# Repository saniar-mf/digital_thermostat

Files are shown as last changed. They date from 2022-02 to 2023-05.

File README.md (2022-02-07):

# digital_thermostat
this project is a Digital Thermostat with arduino nano and SSD1306 128x32 Oled display with DS18B20 Temprature sensor.
this project works with 3.7 li-ion battery and relays can work together.anyway you can use usb charger or adaptor for powering up device.
also you can control your board with serial comminication or USB cable and desktop application.
PCB is ready and you can make it in 1 Layer.
## Board
board



-**In top-right you can change Relays source with jumpers between battery and adaptor jack**

-**You can choose the regulator based on the voltage of your relays**

-**If the relays are connected to the battery voltage source
Replace regulator َU1 with 15 ohm SMD resistor**

_**Remember Serial Comminication is for 3.3V so when you run your board with battery if your bluetooth madule had resistor in RX pin it filter your comminication.
best way is using bluetooth madules without boards or shorting RX in resistor**

## Serial Comminication
### board sends us this messages.
Prefix| Message | Description |
--- | --- | --- |
SN+| SettingUp | First Message when device turned on |
SN+| FirstStart | Board never used before |
SN+| Ready | Setup complite and ready to work |
SN+| SensorDetached | DS18B20 is not available |
SN+| SensorAttached | when sensor problem solved |
SN+| BatteryLow | Battery voltage is less than 3.75V and device not works |
SN+| BatteryOK | After connecting the charger and increasing the battery voltage to 3.75 volts |
SN+| SettingUpdate | When making changes to settings |
SN+| HT | Temperature is more than maximum temperature |
SN+| LT | Temperature is less than minimum temperature |
SN+| HPT | Temperature is more than (2/3 Avrage minimum and maximum) |
SN+| LPT | Temperature is less than (1/3 Avrage minimum and maximum) |
SN+| FIT | The temperature rises rapidly |
SN+| FDT | The temperature drops rapidly |
SN+| Normal | Temprature is normal |
SN+| {float} | Temprature value |

-**SN :To identify the message center (prevents interference if multiple boards are used)**

-**All messages are sent only once and are not repeated.If the temperature does not change, a new temperature message will not be sent**
### Getting information from board:
#### Commands:

 Command | response |
 --- | --- |
Get+ | SN+Temp+MinTemp+MaxTemp+AlarmEnable+HeaterEnable+CoolerEnable+VccVoltage+PowerSavingMode|
Get+T+ | SN+Temp |

Command | response |
 --- | --- |
 Set+MaxTemp+MinTemp+AlarmEnable+HeaterEnable+CoolerEnable+PowerSavingMode | SettingUpdate
  
  -If you do not want to change the numerical values, replace it with 200 and for logical values, replace it with 2 

## Desktop Application

psc1

writed with python and Qt5 can be used in Linux and Windows

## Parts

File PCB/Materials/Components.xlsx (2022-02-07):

Comment | Description | Designator | Footprint | LibRef | Quantity
TP4056 | li ion charger board | B1 | TP4056 | TP4056 | 1
Battery | Multicell Battery | BT1 | BAT-2 | Battery | 1
10uf | Polar Capacitor | C1 | cap 00 | Cap-Polar | 1
47uf | Polar Capacitor | C2 | cap 01 | Cap-Polar | 1
220uf | Polar Capacitor | C3 | cap 03 | Cap-Polar | 1
22uf | Polar Capacitor | C4 | cap 00 | Cap-Polar | 1
Diode 1N4007 | 1 Amp General Purpose Rectifier | D1, D3 | DO-41 | Diode 1N4007 | 2
CoLED | Blue LED for Cooler | D2, D4 | LED_5MM | LED | 2
Power Jack | Power Jack | J1 | Power Jack | Power Jack | 1
Relay-12vDC | Cooler Relay, Heater Relay | K1, K2 | Relays | Relay-05vDC | 2
Buzzer | Buzzers Transducer, Externally Driven Piezo 3V 4kHz 60dB @ 3V, 10cm Through Hole PC Pins | LS | XDCR_PS1240P02BT | PS1240P02BT | 1
LCD | I2C Oled | P1 | HDR1X4 | Header 4 | 1
DS18B20 | Header, 3-Pin | P2 | HDR1X3 | Header 3 | 1
Serialout | Header, 4-Pin | P3 | HDR1X4 | Header 4 | 1
RelayVCC | Header, 3-Pin | PR | HDR1X3 | Header 3 | 1
BD139 | NPN Transistor | Q1, Q2 | SOT-32 | BD139 | 2
180R | Resistor | R1, R4 | Res-(1/4) | Resistor | 2
1K | Resistor | R2, R5 | Res-(1/4) | Resistor | 2
4.7K | Resistor | R3 | Res-(1/4) | Resistor | 1
RPot | Potentiometer | R6 | VR5 | RPot | 1
10K | Resistor | R7, R8 | Res-(1/4) | Resistor | 2
1 | Resistor | R9 | RES 1206 (3216X08L) | Resistor | 1
Switch SPDT_Subminiator | Subminiator SPDT Switch | S1 | SPDT Subminiator | Switch SPDT_Subminiator | 1
Change | Push Button Switch | S2 | Switch - Push to On | Switch PB | 1
Mode | Push Button Switch | S3 | Switch - Push to On | Switch PB | 1
Terminal | Cooler Terminal, Heater Terminal | T1, T2 | Terminal 1*3 | Terminal 1*3 | 2
LM1117IMP-3.3 | 3.3V Requlator. if you use 3V relay Replace it with 15ohm Resistor :) | U1 | MP04A_N | LM1117IMP-x.x | 1
LM1117IMP-5.0 | x.x Volt, 800mA Low-Dropout Linear Regulator, 4-pin SOT-223 | U3 | MP04A_N | LM1117IMP-x.x | 1
Arduino Nano |  | UM | PCBComponent_1 | Component_1 | 1

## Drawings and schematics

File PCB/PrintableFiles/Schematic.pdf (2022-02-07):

# RelayVCC RelayVcc

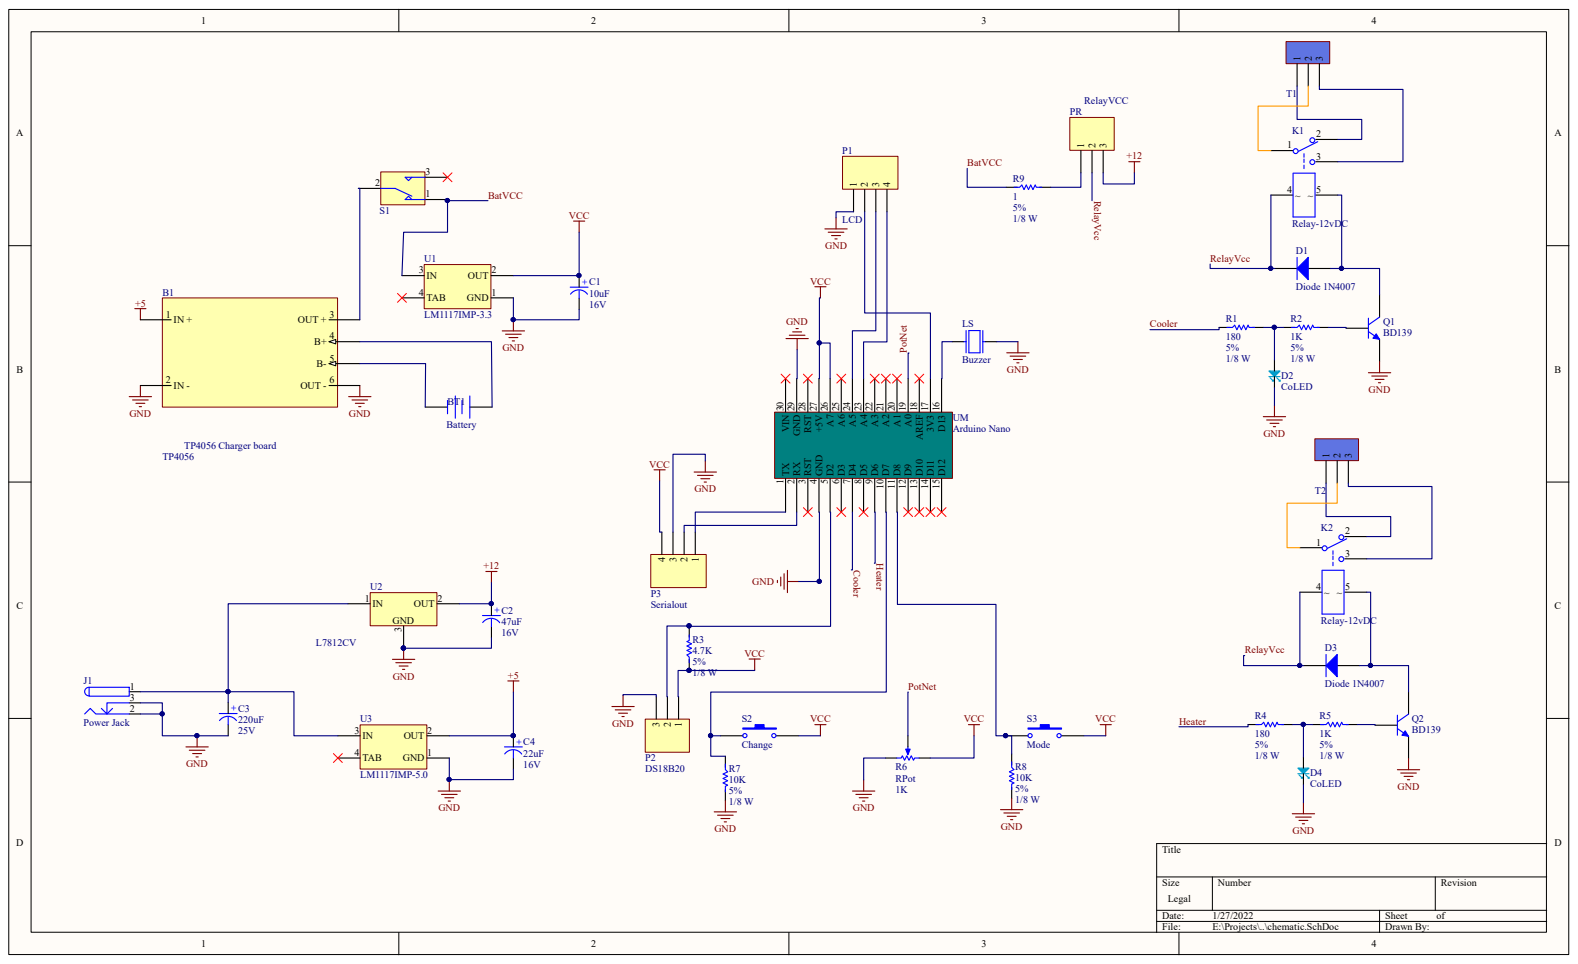
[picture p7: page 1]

9 D7 10 D8 11 D9 12 D10 13 D11 14 D12 15 D13 16 3V3 17 AREF 18 A0 19 A1 20 A2 21 A3 22 A4 23 A5 24 A6 25 A7 26 +5V 27 RST 28 GND 29 VIN 30

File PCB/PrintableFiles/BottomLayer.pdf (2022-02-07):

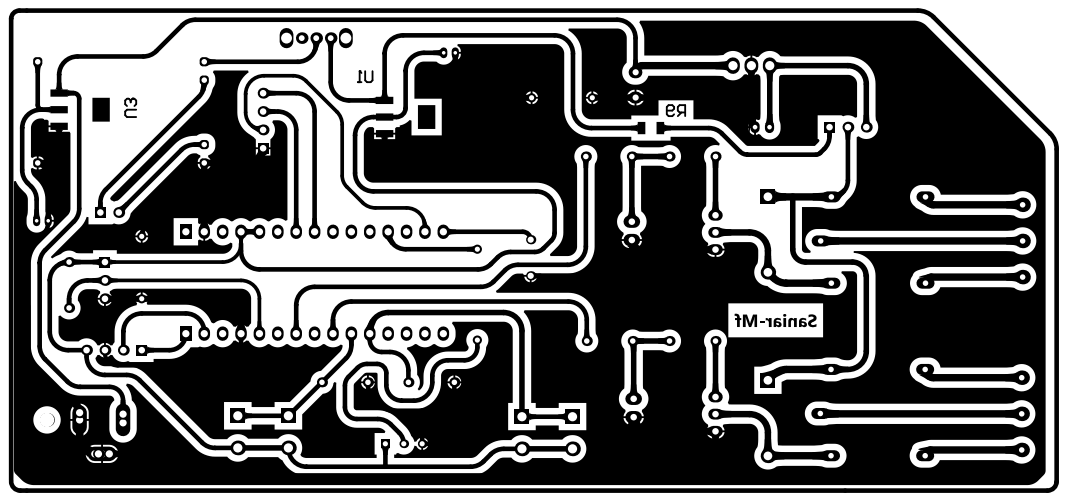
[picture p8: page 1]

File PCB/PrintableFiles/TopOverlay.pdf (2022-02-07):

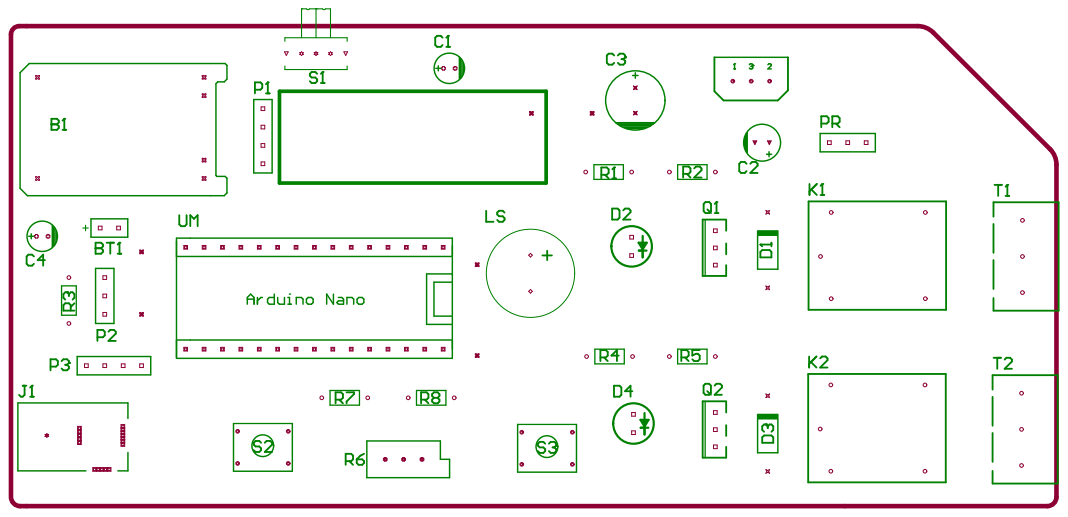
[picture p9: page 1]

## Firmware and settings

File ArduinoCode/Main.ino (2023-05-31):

/*

Auth : Saniar_Mf
My Github : https://github.com/saniar-mf

*/

// importing librarys
#include <Arduino.h>
#include <EEPROM.h>
#include <SPI.h>
#include <U8g2lib.h>
#include <Wire.h>

#include <math.h>
#include <stdio.h>
#include <stdlib.h>
#include <string.h>

#include <DallasTemperature.h>
#include <OneWire.h>

// Defining Ports and Protocols
#define ONE_WIRE_BUS 2

#define Buzzer 13
#define Heater 6
#define Cooler 4

#define Volume A0
#define SourceVoltage A7 //we don't need this in this project

#define ModeSW 8
#define ChangeSW 7

OneWire oneWire(ONE_WIRE_BUS);

DallasTemperature TempSensors(&oneWire);

U8G2_SSD1306_128X32_UNIVISION_F_HW_I2C u8g2(U8G2_R0); // Connected to arduino I2C

// Main Values
float Temp1;
float MaxTemp;
float MinTemp;

bool Alarm = 0;
bool HeaterState = 0;
bool CoolerState = 0;

bool Place = 0;
uint8_t Item = 0;

float TempLog[8];
uint8_t SN = 123;
uint8_t Status = 91;
uint8_t BTStatus = 53;
bool PowerSave = 0;
//EEPROM Memory address
const char AdAlarm = 0;
const char AdHS = 1;
const char AdCS = 2;

const char AdMax = 3;
const char AdMin = 8;

void setup(void)
{
    Serial.begin(9600);

    pinMode(Buzzer, OUTPUT);
    pinMode(Heater, OUTPUT);
    pinMode(Cooler, OUTPUT);
    pinMode(SourceVoltage, INPUT);

    Serial.write(SN);
    Serial.println("SettingUp");
    bool BT = 0;
    // This Codes is for checking EEPROM and if was True it means that this is first start afret uploading code and after putting default valuess in EEPROM
    if (EEPROM.read(0) == 255 and EEPROM.read(1) == 255 and EEPROM.read(2) == 255)
    {
        EEPROM.put(AdMax, 30.0);
        EEPROM.put(AdMin, 20.0);
        EEPROM.put(AdAlarm, 1);
        EEPROM.put(AdHS, 1);
        EEPROM.put(AdCS, 1);
        EEPROM.put(14, BT); // if battery was low and mcu reset all the time when checking relays
        Serial.println("FirstStart");
        delay(400);
    }
    // Getting Values from EEPROM memory
    EEPROM.get(AdMax, MaxTemp);
    EEPROM.get(AdMin, MinTemp);
    EEPROM.get(AdAlarm, Alarm);
    EEPROM.get(AdHS, HeaterState);
    EEPROM.get(AdCS, CoolerState);
    EEPROM.get(14, BT);
    // main start up
    u8g2.begin();
    TempSensors.begin();
    u8g2.clearBuffer();                    // clear the internal memory
    u8g2.setFont(u8g2_font_logisoso18_tr); // suitable fonts from https://github.com/olikraus/u8g2/wiki/fntlistall
    u8g2.drawStr(10, 30, "Saniar_Mf");
    u8g2.sendBuffer(); // transfer internal memory to the display

    if (BT == 0 || GetBattery() <= 3.75)
    {
        BatteryLow();
    }

    digitalWrite(Heater, LOW);
    digitalWrite(Cooler, HIGH);
    digitalWrite(Buzzer, LOW);
    delay(100);
    digitalWrite(Buzzer, Alarm);
    delay(100);
    digitalWrite(Buzzer, LOW);
    delay(100);
    digitalWrite(Buzzer, Alarm);
    delay(100);
    digitalWrite(Buzzer, LOW);
    delay(200);
    digitalWrite(Heater, HIGH);
    digitalWrite(Cooler, LOW);
    digitalWrite(Buzzer, Alarm);
    u8g2.setPowerSave(PowerSave);
    u8g2.clearBuffer();
    u8g2.drawStr(30, 30, "Ready");
    u8g2.sendBuffer();
    TempSensors.requestTemperatures();
    Temp1 = TempSensors.getTempCByIndex(0);
    if(Temp1<=-126){
        InsertSensor();
    }
    for (int i = 0; i < 8; i++)
    {
        TempLog[i] = Temp1;
    }

    delay(100);
    digitalWrite(Buzzer, LOW);
    digitalWrite(Cooler, LOW);
    digitalWrite(Heater, LOW);
    Serial.println("Ready");
    delay(100);
    EEPROM.put(14, 1);
}

void loop(void)
{
    // Serial.println(GetBattery());
    if (GetBattery() <= 3.75)
    {
        BatteryLow();
    }
    if (Serial.available() > 0)
    {
        SerialParser();
    }
    if (Place == 0)
    { // in main meno
        if (digitalRead(ModeSW) == 1)
        {
            delay(30);
            if (digitalRead(ModeSW) == 1)
            {
                Place = 1;
                delay(70);
                Setting();
            }
        }
        else
        {
            MainSC();
            delay(500);
        }
    }
    else if (Place == 1)
    { // in Setting Meno
        if (digitalRead(ModeSW) == 1)
        {
            delay(30);
            if (digitalRead(ModeSW) == 1)
            {
                Item += 1;
                delay(70);
            }
        }
        Setting();
    }
}

// this function make Temp string from temprature value to make show able in display
void getString(char *str)
{
    char s[7];
    char *sign = "-";
    if (Temp1 >= 0)
    {
        sign = "";
    }
    int d = abs(Temp1);
    int a = (int)((fabs(Temp1) - (float)d) * 10);
    snprintf(s, 7, "%s%d.%d", sign, d, a);
    strcpy(str, s);
}
// this function make Min\Max string from values to make show able in display
void getMaxMin(char *Max, char *Min)
{
    char MaxStr[7];
    char MinStr[7];

    char *signM = "-";
    char *signm = "-";

    if (MaxTemp >= 0.0)
    {
        signM = "";
    }
    if (MinTemp >= 0.0)
    {
        signm = "";
    }

    int dM = abs((int)MaxTemp);
    int aM = (int)((fabs(MaxTemp) - (float)dM) * 10);
    snprintf(MaxStr, 7, "%s%d.%d", signM, dM, aM);

    int dm = abs((int)MinTemp);
    int am = (int)((fabs(MinTemp) - (float)dm) * 10);
    snprintf(MinStr, 7, "%s%d.%d", signm, dm, am);

    strcpy(Min, MinStr);
    strcpy(Max, MaxStr);
}
void SerialParser()
{
    String DATA = Serial.readString();
    // PostMethod = Set+MaxTemp+MinTemp+AlarmState+HeaterState+CoolerState+PowerSavingMode
    // GetMethod =i will send:SN+Temp+MinTemp+MaxTemp+AlarmState+HeaterState+CoolerState+VccVoltage+PowerSavingMode
    String Pieces[7] = {"Set", "200", "200", "2", "2", "2","2"};
    Pieces[0] = DATA.substring(0, DATA.indexOf("+"));

    uint8_t lastIndex = DATA.indexOf("+"), i = 1;

    while (lastIndex < DATA.length() and i < 7)
    {
        Pieces[i] = DATA.substring(lastIndex + 1, DATA.indexOf("+", lastIndex + 1));
        lastIndex = DATA.indexOf("+", lastIndex + 1);
        i++;
    }

    if (Pieces[0] == "Set")
    {
        if (Pieces[1].toInt() < 125 && Pieces[1].toInt() > -50)
        { // MaxTemp
            
            MaxTemp = Pieces[1].toInt();
            float DF = MaxTemp - MinTemp;
            if (DF <= 1)
            {
                MinTemp = MaxTemp - 1;
            }
        }
        if (Pieces[2].toInt() < 125 && Pieces[2].toInt() > -50)
        { // MinTemp
            MinTemp = Pieces[2].toInt();
            float DF = MaxTemp - MinTemp;
            if (DF <= 1)
            {
                MaxTemp = MinTemp + 1;
            }
        }
        if (Pieces[3].toInt() < 2 && Pieces[3].toInt() >= 0)
        { // Alarm State
            Alarm = Pieces[3].toInt();
        }
        if (Pieces[4].toInt() < 2 && Pieces[4].toInt() >= 0)
        { // Heater State
            HeaterState = Pieces[4].toInt();
        }
        if (Pieces[5].toInt() < 2 && Pieces[5].toInt() >= 0)
        { // Cooler State
            CoolerState = Pieces[5].toInt();
        }
        if (Pieces[6].toInt() < 2 && Pieces[6].toInt() >= 0)
        { // Cooler State
            PowerSave = Pieces[6].toInt();
            u8g2.setPowerSave(PowerSave);
        }
        WriteEEPROM();
    }
    else if (Pieces[0] == "Get")
    { 
        if(Pieces[1]=="T"){
          String infos = String(SN)+"+"+String(Temp1);          
          Serial.println(infos);
        }
        else{

        
      // 7% of memory!!!
        //       send:SN+Temp+MinTemp+MaxTemp+AlarmState+HeaterState+CoolerState+VccVoltage+PowerSavingMode
        String infos = String(SN)+"+"+String(Temp1)+"+"+String(MaxTemp)+"+"+String(MinTemp)+"+"+String(Alarm)+"+"+String(HeaterState)+"+"+String(CoolerState)+"+"+(GetBattery())+"+"+String(PowerSave);
        Serial.println(infos);
        // Serial.println("ST+123");
        // Serial.println(Temp1);
        // Serial.println(MaxTemp);
        // Serial.println(MinTemp);
        // Serial.println(Alarm);
        // Serial.println(HeaterState);
        // Serial.println(CoolerState);
        // Serial.println(GetBattery());
        // Serial.println("End+123");
    }
    }
}
void InsertSensor(){
    delay(200);
    TempSensors.requestTemperatures();
    Temp1 = TempSensors.getTempCByIndex(0);
    if(Temp1<=-126){
        u8g2.clearBuffer();
        u8g2.setFont(u8g2_font_profont12_tr);
        u8g2.drawStr(16, 22, "!Insert DS18B20!");
        u8g2.sendBuffer();
        digitalWrite(Heater, LOW);
        digitalWrite(Cooler, LOW);
        Serial.println("SensorDetached");
        bool al = 0;
        while (1)
        {
            digitalWrite(Buzzer,al);
            al = !al;
            TempSensors.requestTemperatures();
            Temp1 = TempSensors.getTempCByIndex(0);
            if(Temp1>=-125){
                break;
            }
            delay(500);
        }  
        Serial.println("SensoreAttached");
    }

    
}
void BatteryLow()
{

    delay(200); // this delay is because in a moments relays get on use too many current and so battery voltage get decrease for a moment.
    if (GetBattery() <= 3.75)
    {
        Serial.println("BatteryLow");
        Serial.println(GetBattery());
        EEPROM.update(14, 0);
        u8g2.clearBuffer();
        u8g2.setFont(u8g2_font_battery19_tn);
        u8g2.drawGlyph(60, 26, BTStatus);
        u8g2.sendBuffer();
        digitalWrite(Heater, LOW);
        digitalWrite(Cooler, LOW);
        
        bool al = 0;
        while (GetBattery() <= 3.7)
        {
            delay(1000);
            digitalWrite(Buzzer,al);
            al != al;
        }
    }
    Serial.println("BatteryOK");
}
float GetBattery()
{
    long result;
    // Read 1.1V reference against AVcc
    ADMUX = _BV(REFS0) | _BV(MUX3) | _BV(MUX2) | _BV(MUX1);
    delay(2);            // Wait for Vref to settle
    ADCSRA |= _BV(ADSC); // Convert
    while (bit_is_set(ADCSRA, ADSC));
    result = ADCL;
    result |= ADCH << 8;
    result = 1126400L / result; // Back-calculate AVcc in mV
    float Voltage = (float)result / 1000;//Converting mV to V
    Voltage += Voltage * 0.1;//there is a problem in reading VCC that resalt is 90% of Real VCC.
    if (Voltage >= 4.2)
    {
        BTStatus = 53;
    }
    else if (Voltage >= 4.0)
    {
        BTStatus = 52;
    }
    else if (Voltage >= 3.9)
    {
        BTStatus = 51;
    }
    else if (Voltage >= 3.8)
    {
        BTStatus = 49;
    }
    else
    {
        BTStatus = 48;
    }
    return Voltage;
}
void Setting()
{
    TempSensors.requestTemperatures();
    Temp1 = TempSensors.getTempCByIndex(0);
    if(Temp1<=-126){
        InsertSensor();
    }
    u8g2.clearBuffer();
    char MaxStr[7];
    char MinStr[7];
    getMaxMin(MaxStr, MinStr);
    u8g2.setFont(u8g2_font_profont12_tr);
    u8g2.drawStr(3, 12, "Max: ");
    unsigned char width = u8g2.getStrWidth("Max: ");
    u8g2.drawStr(width, 12, MaxStr);
    u8g2.drawStr(3, 31, "Min: ");
    u8g2.drawStr(width, 31, MinStr);
    if (u8g2.getStrWidth(MaxStr) >= u8g2.getStrWidth(MinStr))
    {
        width += u8g2.getStrWidth(MaxStr);
    }
    else
    {
        width += u8g2.getStrWidth(MinStr);
    }

    if (Item == 0)
    { // MaxTemp
        int VolumeV = (analogRead(Volume) / 4) - 131;
        if (VolumeV - 1 > MinTemp)
        {
            MaxTemp = VolumeV;
        }
        u8g2.drawRFrame(1, 1, width + 1, 15, 1);
        // Drawing Frame
    }
    else if (Item == 1)
    { // MinTemp
        int VolumeV = (analogRead(Volume) / 4) - 131;
        if(VolumeV<-50){
          VolumeV = -50;
        }
        if (VolumeV + 1 < MaxTemp)
        {
            MinTemp = VolumeV;
        }
        u8g2.drawRFrame(1, 19, width + 1, 15, 1);
    }
    else if (Item == 2)
    { // Alarm
        u8g2.drawRFrame(width + 7, 5, 22, 22, 1);
        if (digitalRead(ChangeSW) == 1)
        {
            delay(40);
            if (digitalRead(ChangeSW) == 1)
            {
                if (Alarm == 1)
                {
                    Alarm = 0;
                    digitalWrite(Buzzer, LOW);
                }
                else
                {
                    Alarm = 1;
                }
                delay(160);
            }
        }
    }
    else if (Item == 3)
    { // Heater
        u8g2.drawRFrame(width + 30, 5, 22, 22, 1);
        if (digitalRead(ChangeSW) == 1)
        {
            delay(40);
            if (digitalRead(ChangeSW) == 1)
            {
                if (HeaterState == 1)
                {
                    HeaterState = 0;
                    digitalWrite(Heater, LOW);
                }
                else
                {
                    HeaterState = 1;
                }
                delay(160);
            }
        }
    }
    else if (Item == 4)
    { // Cooler
        u8g2.drawRFrame(width + 51, 5, 22, 22, 1);
        if (digitalRead(ChangeSW) == 1)
        {
            delay(40);
            if (digitalRead(ChangeSW) == 1)
            {
                if (CoolerState == 1)
                {
                    CoolerState = 0;
                    digitalWrite(Cooler, LOW);
                }
                else
                {
                    CoolerState = 1;
                }
                delay(160);
            }
        }
    }

    // Drawing Icons
    u8g2.setFont(u8g2_font_open_iconic_play_2x_t);

    width += 5;
    if (Alarm == 1)
    {
        u8g2.drawGlyph(width + 4, 24, 79);
    }
    else
    {
        u8g2.drawGlyph(width + 4, 24, 81);
    }
    u8g2.setFont(u8g2_font_open_iconic_weather_2x_t);
    if (HeaterState == 1)
    {
        u8g2.drawGlyph(width + 28, 24, 69);
    }
    else
    {
        u8g2.drawGlyph(width + 28, 24, 66);
    }
    u8g2.setFont(u8g2_font_open_iconic_check_2x_t);
    if (CoolerState == 1)
    {
        u8g2.setFont(u8g2_font_open_iconic_arrow_2x_t);
        u8g2.drawGlyph(width + 50, 24, 87);
    }
    else
    {
        u8g2.drawGlyph(width + 50, 24, 66);
    }
    ApplyOuts();

    if (Item == 5)
    {
        WriteEEPROM();
        Place = 0;
        Item = 0;
        u8g2.clearBuffer();
        u8g2.setFont(u8g2_font_open_iconic_check_2x_t);
        u8g2.drawGlyph(56, 24, 65);
        delay(400);
    }
    u8g2.sendBuffer();
}

void MainSC()
{
    TempSensors.requestTemperatures();
    Temp1 = TempSensors.getTempCByIndex(0);
    if(Temp1<=-126){
        InsertSensor();
    }
    u8g2.clearBuffer();
    u8g2.setFont(u8g2_font_logisoso18_tr);

    char str[7];
    getString(str);
    int width_temp = u8g2.getStrWidth(str);
    u8g2.drawStr(1, 30, str);
    u8g2.setFont(u8g2_font_profont12_tr);
    u8g2.drawUTF8(width_temp + 4, 32, "°C");

    char Max[7];
    char Min[7];
    getMaxMin(Max, Min);
    u8g2.drawStr(width_temp + 34, 10, Max);
    u8g2.drawStr(width_temp + 34, 32, Min);
    u8g2.setFont(u8g2_font_open_iconic_arrow_1x_t);

    u8g2.drawGlyph(width_temp + 24, 10, 75); // Max
    u8g2.drawGlyph(width_temp + 24, 31, 72); // Min

    u8g2.setFont(u8g2_font_open_iconic_play_1x_t);
    ApplyOuts();
    // Drawing icons

    if (Alarm == 1)
    {
        u8g2.drawGlyph(4, 9, 79); // Sound
    }
    else
    {
        u8g2.drawGlyph(4, 9, 81);
    }
    u8g2.setFont(u8g2_font_open_iconic_weather_1x_t);
    if (HeaterState == 1)
    {
        u8g2.drawGlyph(16, 9, 69);
    }
    else
    {
        u8g2.drawGlyph(16, 9, 66);
    }
    u8g2.setFont(u8g2_font_open_iconic_arrow_1x_t);
    if (CoolerState == 1)
    {
        u8g2.drawGlyph(28, 9, 87);
    }
    else
    {
        u8g2.setFont(u8g2_font_open_iconic_check_1x_t);
        u8g2.drawGlyph(28, 9, 66);
    }
    u8g2.drawGlyph(40, 9, Status);
    u8g2.setFont(u8g2_font_battery19_tn);
    u8g2.drawGlyph(55, 19, BTStatus);
    u8g2.sendBuffer();
}

void WriteEEPROM()
{
    EEPROM.put(AdMax, MaxTemp);
    EEPROM.put(AdMin, MinTemp);
    EEPROM.put(AdAlarm, Alarm);

    EEPROM.put(AdHS, HeaterState);
    EEPROM.put(AdCS, CoolerState);
    Serial.println("SettingUpdate");
}

void ApplyOuts()
{

    if (Temp1 >= MaxTemp)
    { // temprature is higher than max value
        Status = 68;
        digitalWrite(Buzzer, Alarm);
        digitalWrite(Cooler, CoolerState);
        digitalWrite(Heater, LOW);
        Serial.println("HT");
    }
    else if (Temp1 <= MinTemp)
    { // temprature is lower than min value
        Status = 71;
        digitalWrite(Buzzer, Alarm);
        digitalWrite(Heater, HeaterState);
        digitalWrite(Cooler, LOW);
        Serial.println("LT");
    }
    else if (Temp1 > MaxTemp - ((MaxTemp - MinTemp) / 3))
    { // this means starting cooling when temp is more than 2/3 avrage max-min
        Status = 84;
        digitalWrite(Cooler, CoolerState);
        digitalWrite(Heater, LOW);
        digitalWrite(Buzzer, LOW);
        Serial.println("HPT");
    }
    else if (Temp1 < MinTemp + ((MaxTemp - MinTemp) / 3))
    {// this means starting cooling when temp is less than 1/3 avrage max-min
        Status = 85;
        digitalWrite(Heater, HeaterState);
        digitalWrite(Cooler, LOW);
        digitalWrite(Buzzer, LOW);
        Serial.println("LPT");
    }

    else
    {
        float temp = TempLog[0];
        for (int i = 0; i < 7; i++)
            TempLog[i] = TempLog[i + 1];
        TempLog[7] = temp;
        if (((TempLog[0] + TempLog[1] + TempLog[2] + TempLog[3]) - (TempLog[4] + TempLog[5] + TempLog[6] + TempLog[7])) > 0 and Temp1 < (MaxTemp - MinTemp) / 2)
        { // Ro be kahesh
            if (HeaterState == 1)
            {
                digitalWrite(Heater, HIGH);
                digitalWrite(Cooler, LOW);
                Serial.println("FDT");
            }
        }
        else if (((TempLog[0] + TempLog[1] + TempLog[2] + TempLog[3]) - (TempLog[4] + TempLog[5] + TempLog[6] + TempLog[7])) < 0 and Temp1 > (MaxTemp - MinTemp) / 2)
        { // Ro be AfZayesh
            if (CoolerState == 1)
            {
                digitalWrite(Cooler, HIGH);
                digitalWrite(Heater, LOW);
                Serial.println("FIT");
            }
        }
        else
        {
            digitalWrite(Buzzer, LOW);
            digitalWrite(Cooler, LOW);
            digitalWrite(Heater, LOW);
        }
        Status = 91;
    }
}

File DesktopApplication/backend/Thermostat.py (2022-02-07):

class Thermostat():
    def __init__(self,SN,Temp=0.0,MaxTemp=30.0,MinTemp=20.0,Alarm=1,Heater=1,Cooler=1,PowerSaving=0,BatteryVoltage=4.2,BatteryCapacity=4500):
        self.Temp = Temp
        self.MaxTemp = MaxTemp
        self.MinTemp = MinTemp
        self.Alarm = Alarm
        self.Heater = Heater
        self.Cooler = Cooler
        #0 = disabled - 1 = Enable/NotWorking - 2 = Working
        self.HeaterState = 0
        self.CoolerState = 0
        self.AlarmState = 0
        self.PowerSaving = PowerSaving
        self.SN = SN

        self.BatteryVoltage = BatteryVoltage
        self.Status = "Normal"
        self.BatteryCapacity = BatteryCapacity
    def SetViaAlgoritm(self):
        if (self.Temp >= self.MaxTemp):
            if self.Alarm:self.AlarmState = 2
            else:self.AlarmState = 0
            if self.Cooler:self.CoolerState = 2
            else:self.CoolerState = 0
            if self.Heater:self.HeaterState = 1
            else:self.HeaterState = 0
            self.Status = "HT"

        elif (self.Temp <= self.MinTemp):
            if self.Alarm:self.AlarmState = 2
            else:self.AlarmState = 0
            if self.Cooler:self.CoolerState = 1
            else:self.CoolerState = 0
            if self.Heater:self.HeaterState = 2
            else:self.HeaterState = 0
            self.Status = "LT"
        elif (self.Temp > self.MaxTemp - ((self.MaxTemp - self.MinTemp) / 3)):
            if self.Alarm:self.AlarmState = 1
            else:self.AlarmState = 0
            if self.Cooler:self.CoolerState = 2
            else:self.CoolerState = 0
            if self.Heater:self.HeaterState = 1
            else:self.HeaterState = 0
            self.Status = "HPT"
        elif (self.Temp < self.MinTemp + ((self.MaxTemp - self.MinTemp) / 3)):
            if self.Alarm:self.AlarmState = 1
            else:self.AlarmState = 0
            if self.Cooler:self.CoolerState = 1
            else:self.CoolerState = 0
            if self.Heater:self.HeaterState = 2
            else:self.HeaterState = 0
            self.Status = "LPT"
        
        else:
            if self.Alarm:self.AlarmState = 1
            else:self.AlarmState = 0
            if self.Cooler:self.CoolerState = 1
            else:self.CoolerState = 0
            if self.Heater:self.HeaterState = 1
            else:self.HeaterState = 0
            self.Status = "Normal"

    def SetViaStatus(self,status:str):
        if status == "HT":
            if self.Alarm:self.AlarmState = 2
            else:self.AlarmState = 0
            if self.Cooler:self.CoolerState = 2
            else:self.CoolerState = 0
            if self.Heater:self.HeaterState = 1
            else:self.HeaterState = 0
            self.Status = "HT"

        elif status == "LT":
            if self.Alarm:self.AlarmState = 2
            else:self.AlarmState = 0
            if self.Cooler:self.CoolerState = 1
            else:self.CoolerState = 0
            if self.Heater:self.HeaterState = 2
            else:self.HeaterState = 0
            self.Status = "LT"

        elif status == "HPT":
            if self.Alarm:self.AlarmState = 1
            else:self.AlarmState = 0
            if self.Cooler:self.CoolerState = 2
            else:self.CoolerState = 0
            if self.Heater:self.HeaterState = 1
            else:self.HeaterState = 0
            self.Status = "HPT"

        elif status == "LPT":
            if self.Alarm:self.AlarmState = 1
            else:self.AlarmState = 0
            if self.Cooler:self.CoolerState = 1
            else:self.CoolerState = 0
            if self.Heater:self.HeaterState = 2
            else:self.HeaterState = 0
            self.Status = "LPT"

        elif status == "LPT":
            if self.Alarm:self.AlarmState = 1
            else:self.AlarmState = 0
            if self.Cooler:self.CoolerState = 1
            else:self.CoolerState = 0
            if self.Heater:self.HeaterState = 2
            else:self.HeaterState = 0
            self.Status = "LPT"

        elif status == "FDT":
            if self.Alarm:self.AlarmState = 1
            else:self.AlarmState = 0
            if self.Cooler:self.CoolerState = 1
            else:self.CoolerState = 0
            if self.Heater:self.HeaterState = 2
            else:self.HeaterState = 0
            self.Status = "FDT"

        elif status == "FIT":
            if self.Alarm:self.AlarmState = 1
            else:self.AlarmState = 0
            if self.Cooler:self.CoolerState = 2
            else:self.CoolerState = 0
            if self.Heater:self.HeaterState = 1
            else:self.HeaterState = 0
            self.Status = "FIT"

        elif status == "Normal":
            if self.Alarm:self.AlarmState = 1
            else:self.AlarmState = 0
            if self.Cooler:self.CoolerState = 1
            else:self.CoolerState = 0
            if self.Heater:self.HeaterState = 1
            else:self.HeaterState = 0
            self.Status = "Normal"


    def UpdateFromString(self,RecivedString:str):
        def IsFloat(val):
            try:float(val)
            except:return False
            else:return True
        #SN+Temp+MinTemp+MaxTemp+AlarmState+HeaterState+CoolerState+VccVoltage+PowerSavingMode
        infos_list = RecivedString.split("+")
        for i in range(len(infos_list)):
            try:
                if i == 0 and IsFloat(infos_list[i]):
                    self.SN = int(infos_list[i])
                
                if i == 1 and IsFloat(infos_list[i]):
                    self.Temp = float(infos_list[i])  

                if i == 2 and IsFloat(infos_list[i]):
                    self.MaxTemp = float(infos_list[i])  
                if i == 3 and IsFloat(infos_list[i]):
                    self.MinTemp = float(infos_list[i])  
                if i == 4 and IsFloat(infos_list[i]):
                    self.Alarm = int(infos_list[i])  
                if i == 5 and IsFloat(infos_list[i]):
                    self.Heater = int(infos_list[i])  
                if i == 6 and IsFloat(infos_list[i]):
                    self.Cooler = int(infos_list[i])  
                if i == 7 and IsFloat(infos_list[i]):
                    self.BatteryVoltage = float(infos_list[i])  
                if i == 8 and IsFloat(infos_list[i]):
                    self.PowerSaving = int(infos_list[i])  
            except:pass 
